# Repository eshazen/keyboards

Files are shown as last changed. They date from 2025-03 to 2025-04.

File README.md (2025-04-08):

# Keyboard project(s)

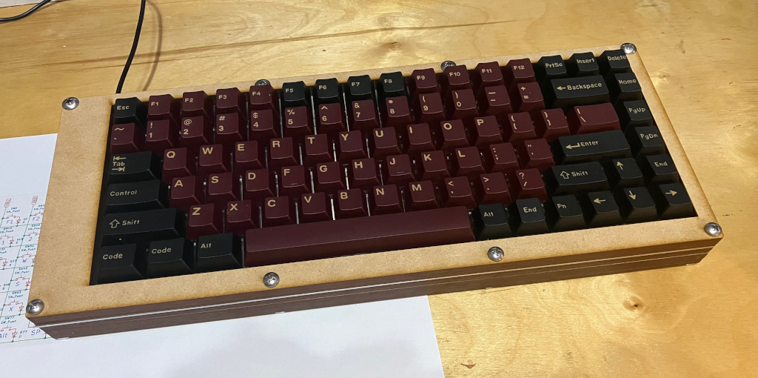
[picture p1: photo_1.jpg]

<p>

## Status

All done, working!  Used QMK for the firmware.  
<br>See `my_84/qmk/eric_84/key` for modified
`keyboard.json` and `keymaps/default/keymap.c`.  
<br>See [README_QMK](README_QMK.md).

To change layout, edit `~/qmk_firmware/keyboards/eric_84_key/keymaps/default/keymap.c`.
Then re-flash with:

    qmk flash -kb eric_84_key -km default

(This can be done "live" as long as you have access to the Arduino reset button).

In summary, created the layout in KLE, generated the plate and case
geometry in `swillkb.com`, and the PCB using the `kbplacer` plugin for
KiCAD.  Firmware generated using `qmk`.

Waterjet cutter files for plate in `waterJet`.

## Tools Used:

* [KLE](https://www.keyboard-layout-editor.com)
* [Plate & Case Builder](http://builder.swillkb.com/) (from [github](https://github.com/vladantrhlik/Keyboard_case_generator?tab=readme-ov-file)).  This generates the DXF for the plate and stacked laser-cut case parts.
* [kbplacer plugin](https://github.com/adamws/kicad-kbplacer) for KiCAD layout

## References

* [PCB video](https://www.youtube.com/watch?v=u13yRbBiRYM&t=10s)
* [Case video](https://www.youtube.com/watch?v=NIIr19TdidY)
* [Building Keyboards with Lasers](https://kbd.news/Building-keyboards-with-lasers-2208.html)
* [Keyboard University](https://www.keyboard.university/)
* [Pro Micro up to 100 pins](https://golem.hu/guide/pro-micro/)

Also used 

## My 84 key

<ul>
    [{a:6},"Esc","F1","F2","F3","F4","F5","F6","F7","F8","F9","F10","F11","F12",{a:7},"PrtSc","Shell","Pause"],
    [{a:4},"~\n`","!\n1","@\n2","#\n3","$\n4","%\n5","^\n6","&\n7","*\n8","(\n9",")\n0","_\n-","+\n=",{a:6,w:2},"Backspace",{a:7},"Insert"],
    [{a:4,w:1.5},"Tab","Q","W","E","R","T","Y","U","I","O","P","{\n[","}\n]",{w:1.5},"|\n\\",{a:6},"Delete"],
    [{w:1.75},"Control",{a:4},"A","S","D","F","G","H","J","K","L",":\n;","\"\n'",{a:6,w:2.25},"Enter","Page Up"],
    [{w:2.25},"Shift",{a:4},"Z","X","C","V","B","N","M","<\n,",">\n.","?\n/",{a:6,w:1.75},"Shift",{a:7},"↑",{a:6},"Page Down"],
    [{a:7,w:1.25},"Home",{a:6,w:1.25},"Menu",{w:1.25},"Alt",{a:7,w:6.25},"",{a:6},"Alt","Fn",{a:7},"End","←","↓","→"]

Using [http://builder.swillkb.com/](http://builder.swillkb.com/).

``` text
    Switch type: MX
	Stab:  Cherry + Costar
	Case: Sandwich
	Holes 8, 4.5mm, 10mm
	Edge:  Top: 10, Left: 30, Right: 10, Bottom: 25
	Corners: 2mm
```
<br>DXFs in `...Case/case1`
<br>PCB in `...kb_test`

This was OK except that the opening in the 'top' was a little tight.
Enlarged the CAD file by .05" on all sides.

</ul>

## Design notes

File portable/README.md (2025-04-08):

# Portable keyboard

Thinking about a portable version of the keyboard, possibly bluetooth.
Possible parts:

* Gateron KS33 low-profile switches
* Gateron low-profile keycap set

Messing with some 3D models it looks as if the total height above
the PCB is about 12mm and about 3mm to bottom of the pins/pegs,
so total around 15mm high.

60% keyboard is 11.25 x 3.75.

## Portable system?

Looking at a full portable system.  Some SBC options:

### RPi 5

Built-in Wifi, but need a hat for eMMC storage.

### Orange Pi

Many confusing pi 5 options.  Some have 2x eMMC
so can do WiFi and storage.  Relatively expensive. 

### ARM OS options

* https://dietpi.com/ - maybe try on a VM?

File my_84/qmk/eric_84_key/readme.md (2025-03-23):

# eric_84_key

eric_84_key

*A short description of the keyboard/project*

* Keyboard Maintainer: [Eric Hazen](https://github.com/eshazen)
* Hardware Supported: *The PCBs, controllers supported*
* Hardware Availability: *Links to where you can find this hardware*

Make example for this keyboard (after setting up your build environment):

    make eric_84_key:default

Flashing example for this keyboard:

    make eric_84_key:default:flash

See the [build environment setup](https://docs.qmk.fm/#/getting_started_build_tools) and the [make instructions](https://docs.qmk.fm/#/getting_started_make_guide) for more information. Brand new to QMK? Start with our [Complete Newbs Guide](https://docs.qmk.fm/#/newbs).

## Bootloader

Enter the bootloader in 3 ways:

* **Bootmagic reset**: Hold down the key at (0,0) in the matrix (usually the top left key or Escape) and plug in the keyboard
* **Physical reset button**: Briefly press the button on the back of the PCB - some may have pads you must short instead
* **Keycode in layout**: Press the key mapped to `QK_BOOT` if it is available

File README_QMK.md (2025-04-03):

# QMK for our keyboard

Following [instructions](https://johnmu.com/basic-qmk-keyboard/)

`qmk new-keyboard`

    Keyboard name:  eric_84_key

Told it our github info, using a dev-board pro-micro and no default layout.
The navigate to `keyboards/eric_84_key` and edit `keyboard.json` to as below
to set matrix pins etc.

Getting a working config was a pain.  The `matrix_pins` came from the schematic.
The `LAYOUT` section was created partly by the (now completely obsolete) https://qmk.fm/converter/
and hand-editing.

In `layout.c` started with a similar layout and hand-edited the changes.

Copied the working `keyboard.json` and `layout.c` to Git at `my_84/qmk/eric_84_key`
in this repo.  

Build instructions:

    qmk compile -kb eric_84_key -km default
	qmk flash -kb eric_84_key -km default
	
No problem reloading "live" keyboard as long as you have access to the reset button.

## Notes on on Xubuntu 24.04 update

(install gcc-avr, avr-libc, avrdude)

Had to use pipx to install in a virtual environment since there doesn't
seem to be an Ubuntu package for qmk.

	$ sudo apt install pipx
    $ pipx install qmk
    $ sudo usermod -a -G dialout $USER

Then fix the link in `.local/bin` to `../share/pipx/venvs/qmk/bin/qmk`

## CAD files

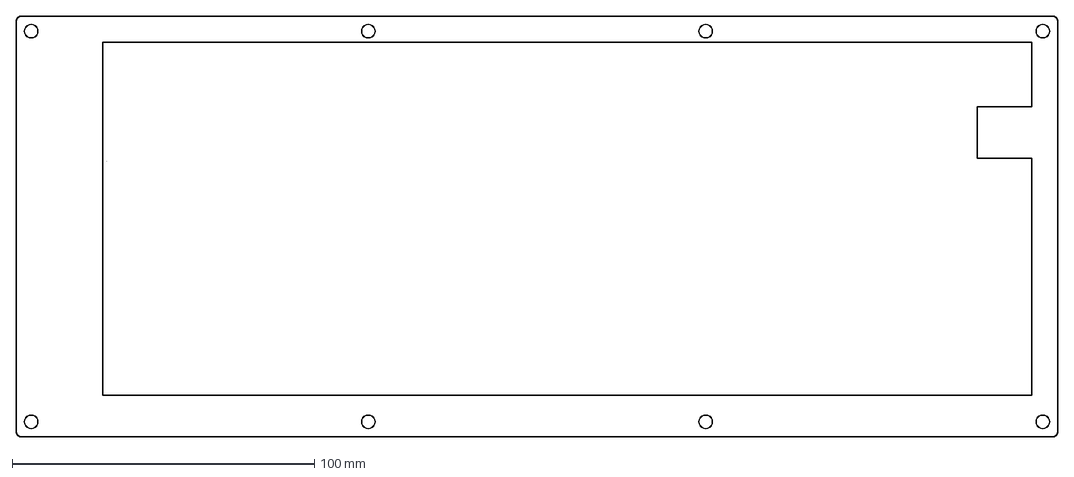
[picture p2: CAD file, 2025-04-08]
Case/case1/top_enlarge_blank.dxf
344.8 x 139.3 mm

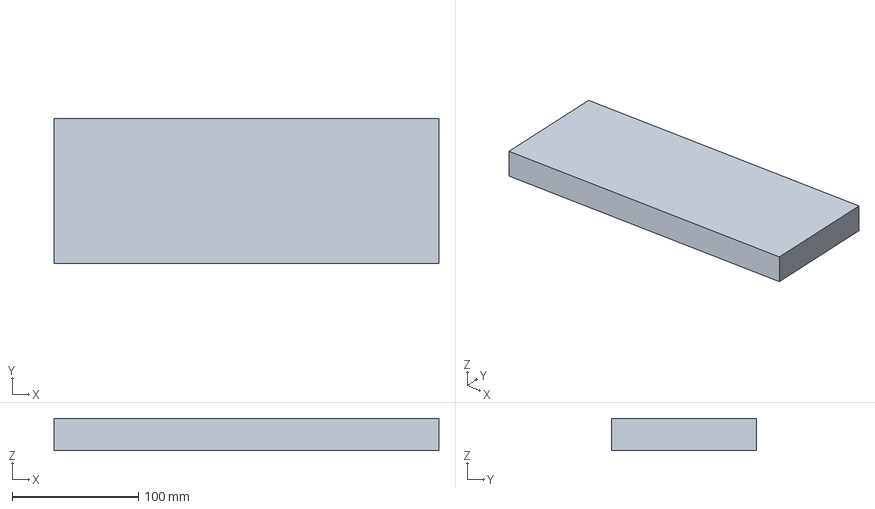
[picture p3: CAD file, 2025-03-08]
Case/test.3mf
305.0 x 115.0 x 25.4 mm

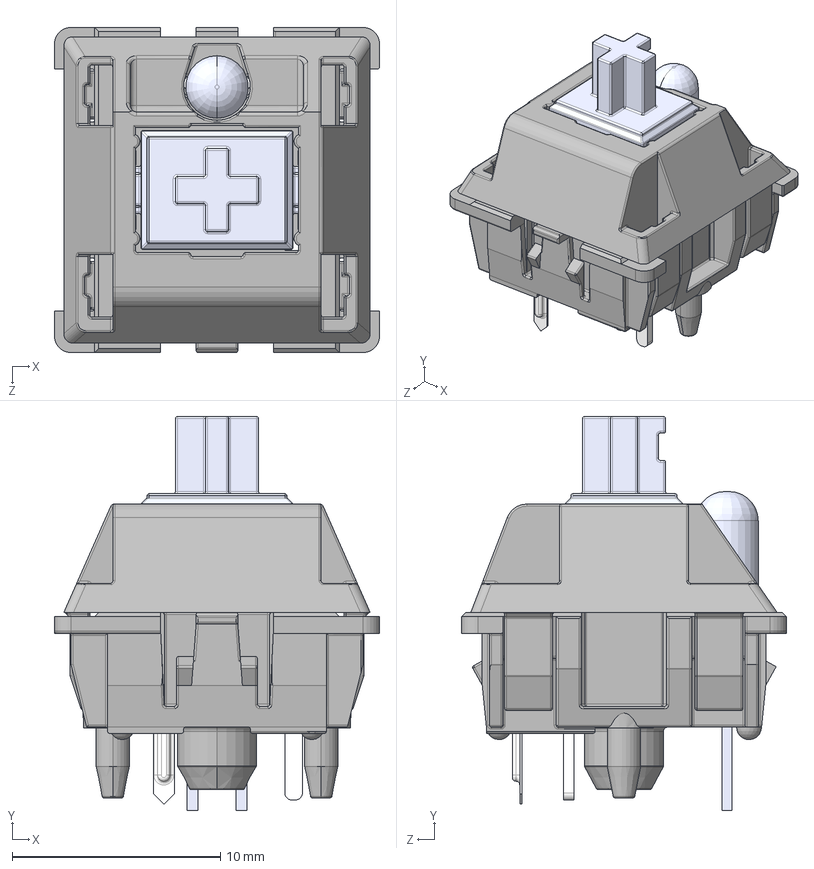
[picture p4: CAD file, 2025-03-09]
kb_test/cherry_mx.step
15.6 x 18.9 x 15.6 mm
MX 轴 按键′_ü___¨1
MX 轴 轴体áì_¨￠¨__
MX粣 拸簽LEDLEDLED
MX轴 轴体 底部 μ×2__默认_á2____è_
针脚___默认__è_

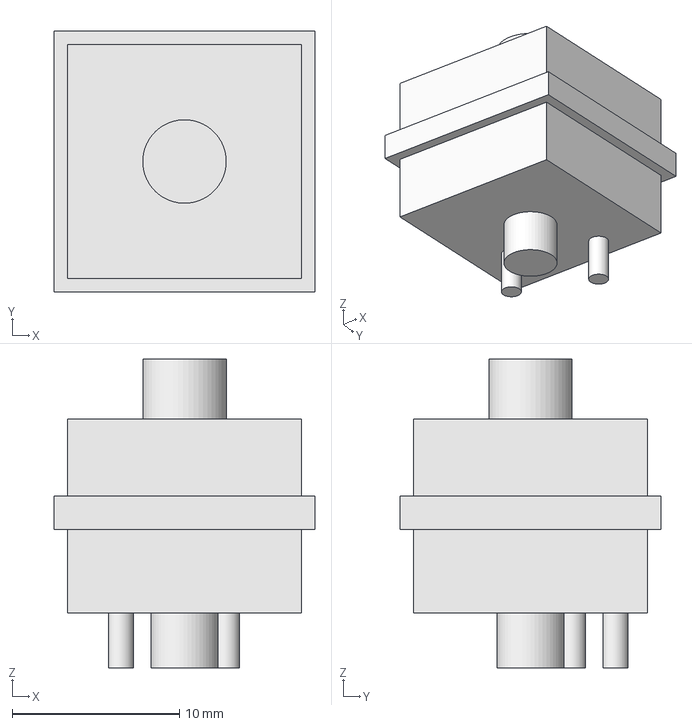
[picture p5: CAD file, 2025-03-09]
kb_test/models/cherry_simple.step
15.6 x 15.6 x 18.5 mm

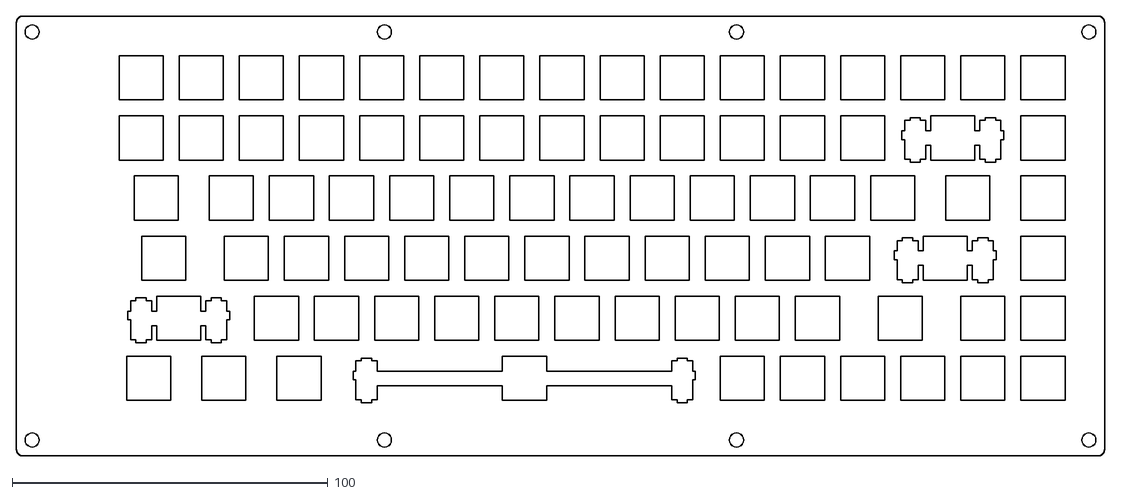
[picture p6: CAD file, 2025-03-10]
plate_fake/switch.dxf
344.8 x 139.3

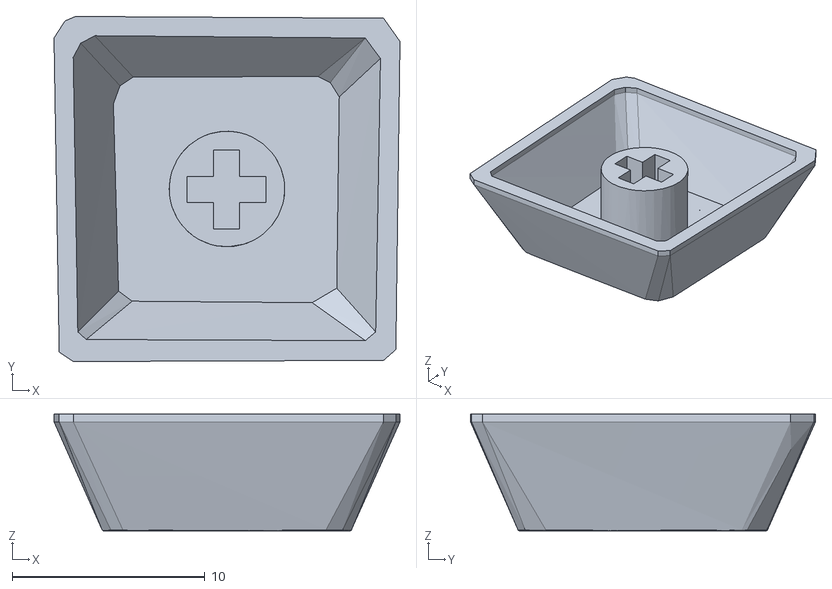
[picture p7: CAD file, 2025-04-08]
portable/gateron-key-cap.stl
18.0 x 17.9 x 6.05

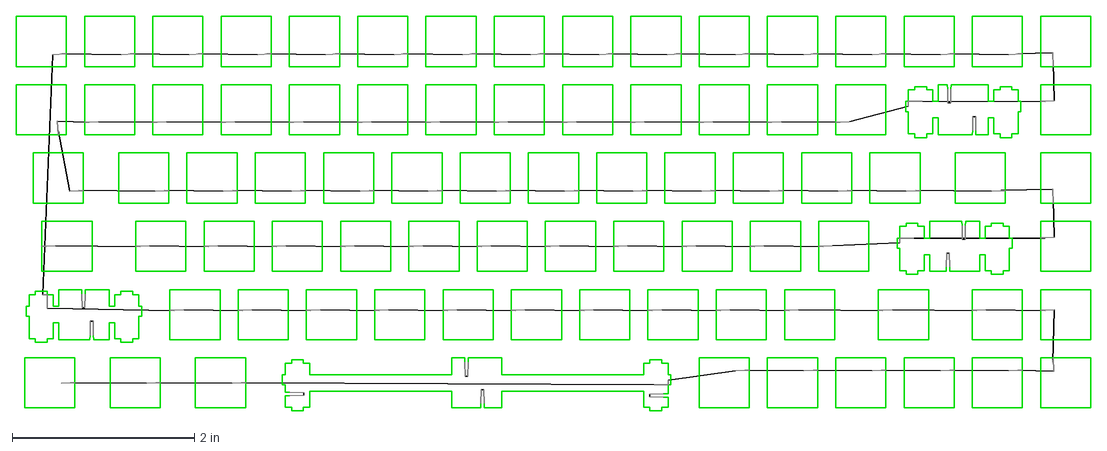
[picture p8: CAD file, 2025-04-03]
waterJet/switch_cutouts_imported_dxf_tabs.dxf
11.8 x 4.33 in

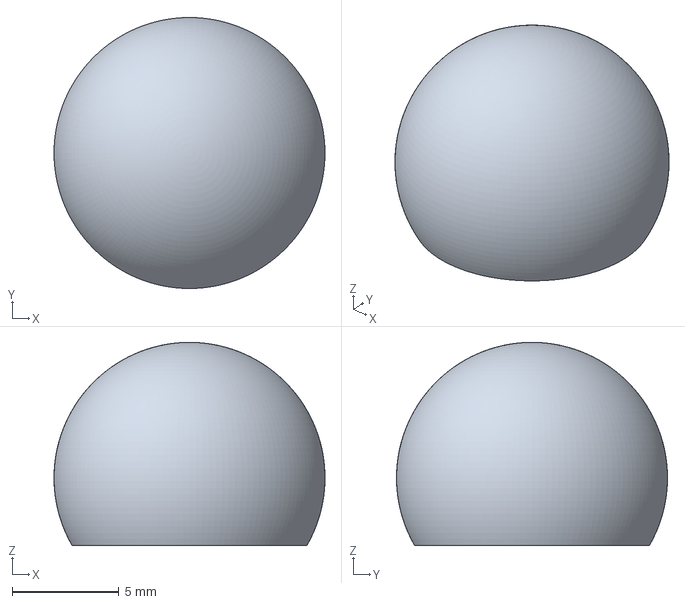
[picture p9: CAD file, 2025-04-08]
Case/case1/foot.3mf
12.7 x 12.7 x 9.52 mm

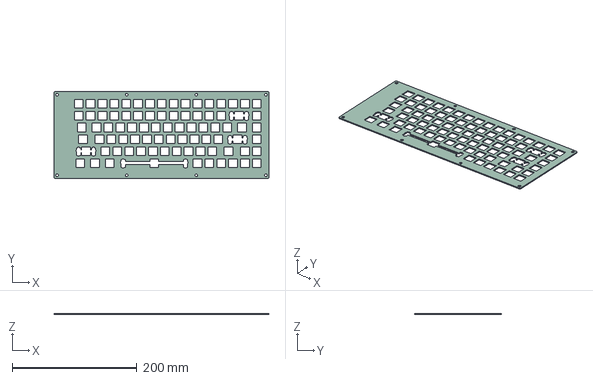
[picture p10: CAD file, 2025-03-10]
plate_fake/plate.step
344.8 x 139.3 x 1.60 mm

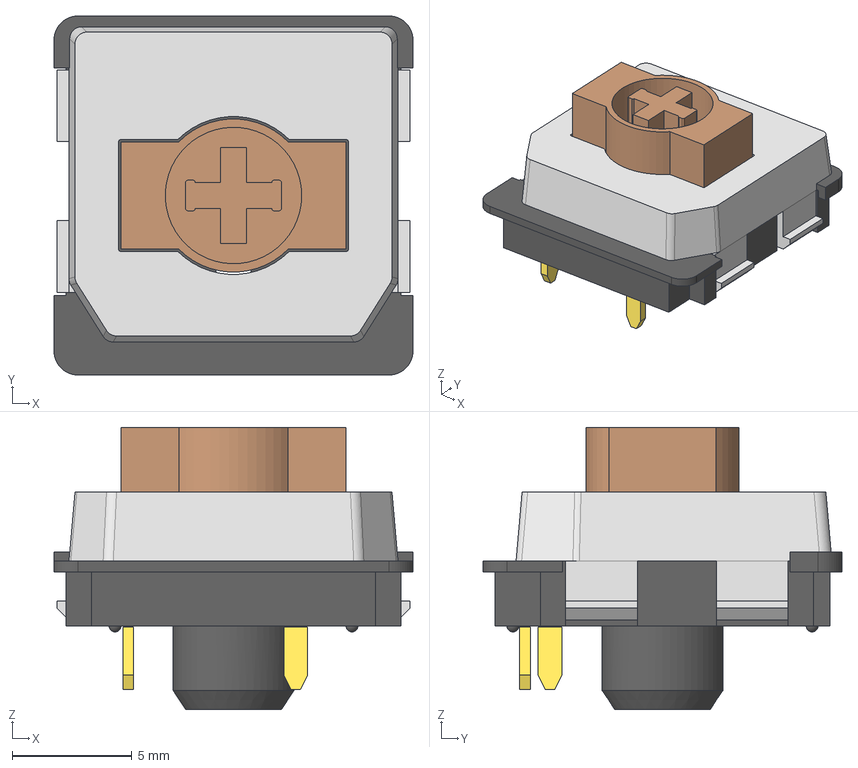
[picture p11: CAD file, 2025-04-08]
portable/ks33.step
15.0 x 15.0 x 11.8 mm
f0684a6a-028c-11ee-ae0e-34c93d8226b1_part
f06a1f0c-028c-11ee-ae0e-34c93d8226b1_part
f1cc5b76-028c-11ee-ae0e-34c93d8226b1_part
f1cc5d06-028c-11ee-ae0e-34c93d8226b1_part
f1cc5d92-028c-11ee-ae0e-34c93d8226b1_part

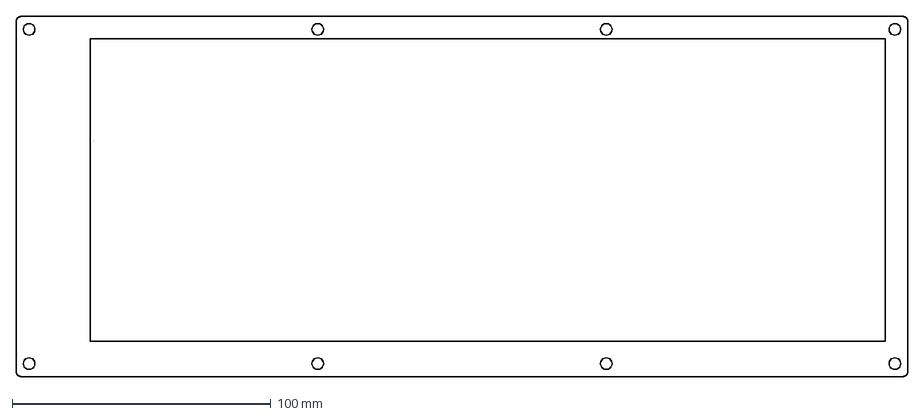
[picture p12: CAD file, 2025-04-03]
Case/case1/top_enlarge.dxf
344.8 x 139.3 mm

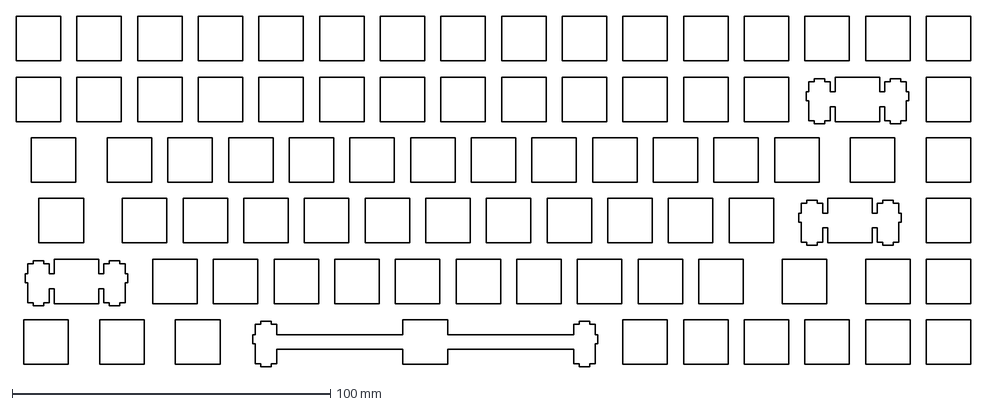
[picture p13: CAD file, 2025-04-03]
Case/case1/switch_cutouts.dxf
299.7 x 110.0 mm

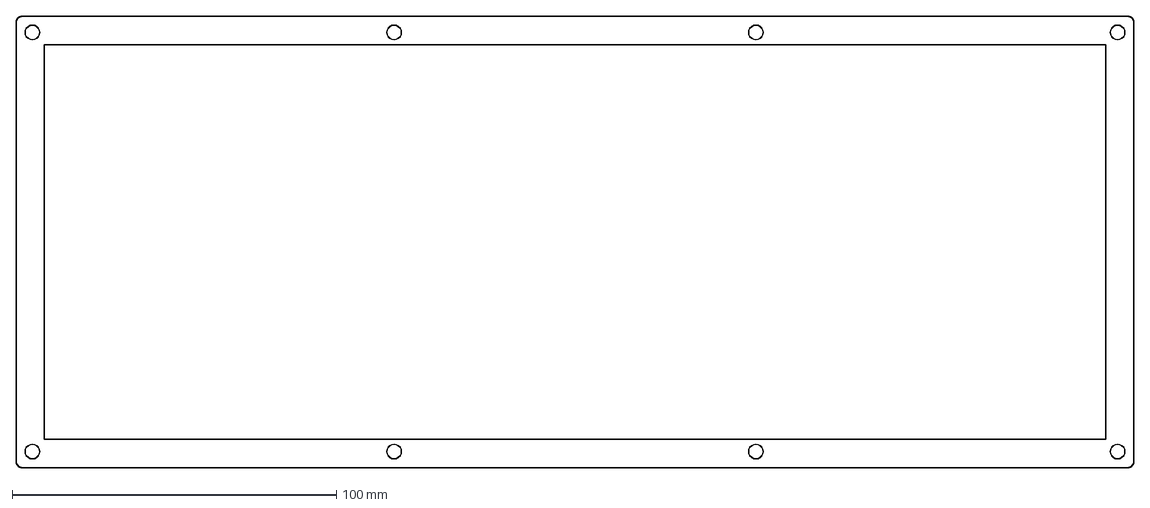
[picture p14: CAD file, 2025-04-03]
Case/case1/closed_enlarge.dxf
344.8 x 139.3 mm

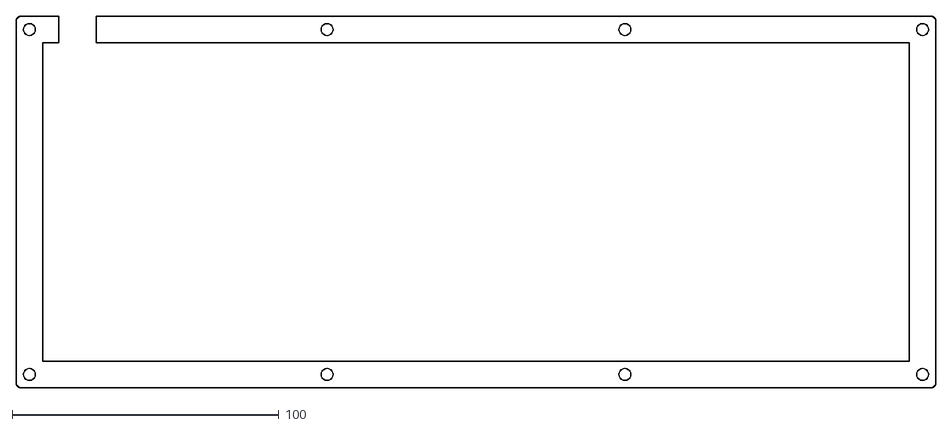
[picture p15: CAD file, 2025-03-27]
Case/case1/open.dxf
344.8 x 139.3

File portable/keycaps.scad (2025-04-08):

include </home/hazen/work/KeyV2/includes.scad>
 
legends = ["0", "1", "2", "3", "4", "5", "6", "7", "8", "9"];


// // use slop if not using a 0.2mm nozzle!
// bar_support() rounded_cherry() row_profile("mt3") tined_stem_support() {
//     key(true);
// }

 
for (x = [0:1:3]) {
  for (y = [0:1:3]) {
    bar_support() rounded_cherry(0.45) tined_stem_support() translate_u(x,y) legend(legends[y*4+x])   dsa_row() {
      // swap the debug()s to render     opposite part
//      debug()  
	 key(true);
//      debug() dished() {
//        legends($inset_legend_depth);
//      }
    }
  }
}

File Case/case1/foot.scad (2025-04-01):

mm = 25.4;
$fn = 128;
e = 0.1;

hole_dia = 0.160*mm;
outer_dia = 0.50*mm;
hole_dep = 0.125*mm;
foot_dep = 0.25*mm;

module foot() {
     difference() {
	  translate( [0, 0, hole_dep])
	       sphere( d=outer_dia);
	  translate( [0, 0, -e])
	       cylinder( d=hole_dia, h=hole_dep);
	  translate( [-outer_dia, -outer_dia, -10])
	       cube( [outer_dia*2, outer_dia*2, 10]);
     }
}

foot();

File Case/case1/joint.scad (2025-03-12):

//
// create overlap joint
//
// joint( w, l, h, right, clear, tap)
//   create (one half of) an overlap joint with drilled holes
//
//   (w, l, h) are (x, y, z) size of entire joint
//   right=true specifies right size
//   (clear, tap) are hole diameters (thru hole from bottom on left side)
//
// (expects mm=25.4)

joint_e = 0.1;

joint_cs_dep = 0.1*mm;		/* countersink depth */
joint_cs_angle = 82;		/* countersink angle */

// make an "ell" for a joint
// size:  wid, leng, dep
// hole:  dia = diameter, outside=1 for start outside, pct = percent to drill
module joint_ell( wid, leng, dep, dia, outside, pct) {
     difference() {
	  cube( [wid, leng, dep]);
	  translate( [wid/2, -e, dep/2])
	       cube( [wid/2+joint_e, leng+2*e, dep/2+joint_e]);
	  // deal with the hole
	  if( outside) {
	       translate( [3*wid/4, leng/2, -e]) {
		    cylinder( d=dia, h = (((pct/2)+1)/100+joint_e)*dep);
		    // countersink
		    ang = 90-joint_cs_angle/2;
		    d_rad = joint_cs_dep/tan(ang);
		    cylinder( d1=dia+2*d_rad, d2=dia, h=joint_cs_dep);
	       }
	  } else {
	       translate( [3*wid/4, leng/2, (dep/2)*(((100-pct)+1)/100)-e])
		    cylinder( d=dia, h = dep/2+2*e);
	  }
     }
}

module joint_flip( wid, leng, dep, flip, dia, outside, pct) {
     if( flip ) {
	  joint_ell( wid, leng, dep, dia, flip, pct);
     } else {
	  translate( [wid, 0, dep])
	       rotate( [180, 0, 180])
	       joint_ell( wid, leng, dep, dia, flip, pct);
     }
}

module joint( w, l, h, right, clear, tap) {
     if( right) {
	  joint_flip(2*w/3, l, h, true, clear, 1, 100);
     } else {
	  joint_flip( 2*w/3, l, h, false, tap, 0, 75);
     }
}

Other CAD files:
Case/case1/foot_round.3mf
Case/case1/case_left.3mf
Case/case1/case_right.3mf
Case/case1/plate_test.3mf
Case/case1/plate.scad
Case/case1/bottom.dxf
Case/case1/closed.dxf
Case/case1/plate.3mf
Case/case1/plate.step
Case/case1/plate.stl
Case/case1/plate_drawing.dxf
Case/case1/test.dxf
Case/case1/test_left.3mf
Case/case1/test_right.3mf
Case/case1/top.dxf
Case/test.scad
kb_test/models/cherry_simple.scad
plate_fake/plate.3mf
portable/ks33.stl
portable/trial_stackup.scad

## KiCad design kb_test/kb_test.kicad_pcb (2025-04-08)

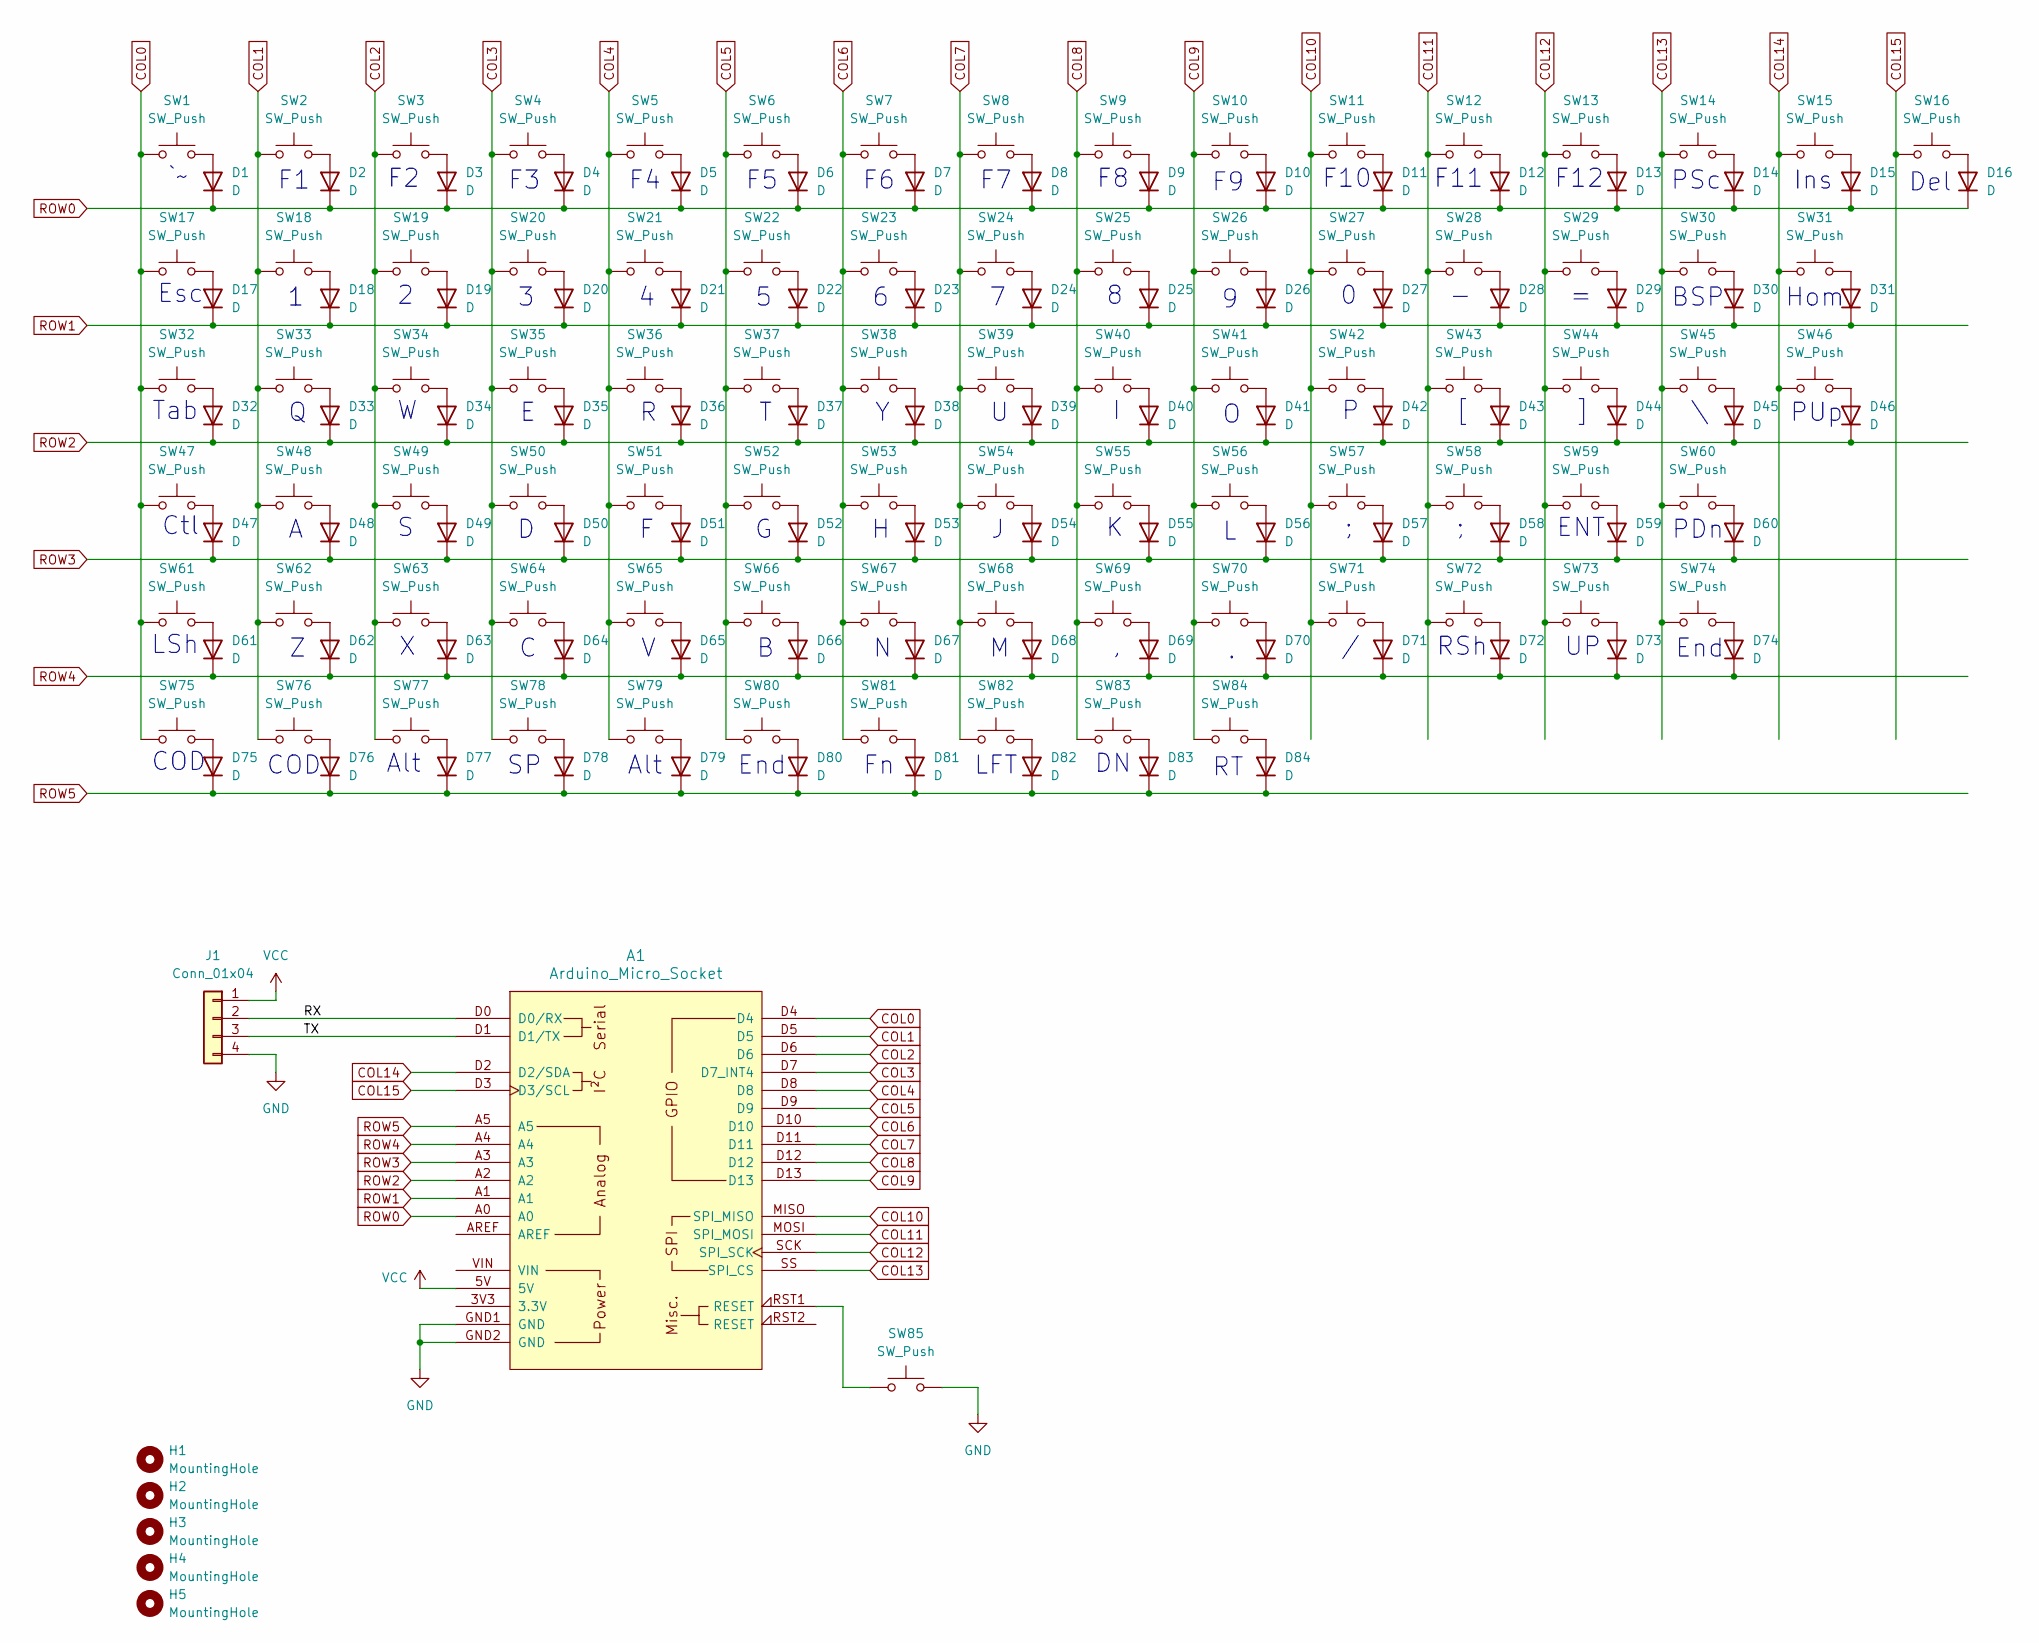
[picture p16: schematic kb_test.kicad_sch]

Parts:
A1: Arduino_Micro_Socket
D1, D2, D3, D4, D5, D6, D7, D8, D9, D10, D11, D12, D13, D14, D15, D16, D17, D18, D19, D20, D21, D22, D23, D24, D25, D26, D27, D28, D29, D30, D31, D32, D33, D34, D35, D36, D37, D38, D39, D40, D41, D42, D43, D44, D45, D46, D47, D48, D49, D50, D51, D52, D53, D54, D55, D56, D57, D58, D59, D60, D61, D62, D63, D64, D65, D66, D67, D68, D69, D70, D71, D72, D73, D74, D75, D76, D77, D78, D79, D80, D81, D82, D83, D84: D; D_DO-41_SOD81_P7.62mm_Horizontal
H1, H2, H3, H4, H5: MountingHole; MountingHole_4.3mm_M4
J1: Conn_01x04; PinHeader_1x04_P2.54mm_Vertical
SW1, SW2, SW3, SW4, SW5, SW6, SW7, SW8, SW9, SW10, SW11, SW12, SW13, SW14, SW15, SW16, SW17, SW18, SW19, SW20, SW21, SW22, SW23, SW24, SW25, SW26, SW27, SW28, SW29, SW30, SW31, SW32, SW33, SW34, SW35, SW36, SW37, SW38, SW39, SW40, SW41, SW42, SW43, SW44, SW45, SW46, SW47, SW48, SW49, SW50, SW51, SW52, SW53, SW54, SW55, SW56, SW57, SW58, SW59, SW60, SW61, SW62, SW63, SW64, SW65, SW66, SW67, SW68, SW69, SW70, SW71, SW72, SW73, SW74, SW75, SW76, SW77, SW78, SW79, SW80, SW81, SW82, SW83, SW84: SW_Push; SW_Cherry_MX_1.00u_PCB
SW85: SW_Push; SW_Tactile_Straight_KSA0Axx1LFTR

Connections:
/RX: A1.D0 (D0/RX), J1.2
/TX: A1.D1 (D1/TX), J1.3
COL0: A1.D4, SW1.1, SW17.1, SW32.1, SW47.1, SW61.1, SW75.1
COL1: A1.D5, SW2.1, SW18.1, SW33.1, SW48.1, SW62.1, SW76.1
COL2: A1.D6, SW3.1, SW19.1, SW34.1, SW49.1, SW63.1, SW77.1
COL3: A1.D7 (D7_INT4), SW4.1, SW20.1, SW35.1, SW50.1, SW64.1, SW78.1
COL4: A1.D8, SW5.1, SW21.1, SW36.1, SW51.1, SW65.1, SW79.1
COL5: A1.D9, SW6.1, SW22.1, SW37.1, SW52.1, SW66.1, SW80.1
COL6: A1.D10, SW7.1, SW23.1, SW38.1, SW53.1, SW67.1, SW81.1
COL7: A1.D11, SW8.1, SW24.1, SW39.1, SW54.1, SW68.1, SW82.1
COL8: A1.D12, SW9.1, SW25.1, SW40.1, SW55.1, SW69.1, SW83.1
COL9: A1.D13, SW10.1, SW26.1, SW41.1, SW56.1, SW70.1, SW84.1
COL10: A1.MISO (SPI_MISO), SW11.1, SW27.1, SW42.1, SW57.1, SW71.1
COL11: A1.MOSI (SPI_MOSI), SW12.1, SW28.1, SW43.1, SW58.1, SW72.1
COL12: A1.SCK (SPI_SCK), SW13.1, SW29.1, SW44.1, SW59.1, SW73.1
COL13: A1.SS (SPI_CS), SW14.1, SW30.1, SW45.1, SW60.1, SW74.1
COL14: A1.D2 (D2/SDA), SW15.1, SW31.1, SW46.1
COL15: A1.D3 (D3/SCL), SW16.1
GND: A1.GND1 (GND), A1.GND2 (GND), J1.4, SW85.2
unnamed: A1.RST1 (RESET), SW85.1
unnamed: D1.2 (A), SW1.2
unnamed: D2.2 (A), SW2.2
unnamed: D3.2 (A), SW3.2
unnamed: D4.2 (A), SW4.2
unnamed: D5.2 (A), SW5.2
unnamed: D6.2 (A), SW6.2
unnamed: D7.2 (A), SW7.2
unnamed: D8.2 (A), SW8.2
unnamed: D9.2 (A), SW9.2
unnamed: D10.2 (A), SW10.2
unnamed: D11.2 (A), SW11.2
unnamed: D12.2 (A), SW12.2
unnamed: D13.2 (A), SW13.2
unnamed: D14.2 (A), SW14.2
unnamed: D15.2 (A), SW15.2
unnamed: D16.2 (A), SW16.2
unnamed: D17.2 (A), SW17.2
unnamed: D18.2 (A), SW18.2
unnamed: D19.2 (A), SW19.2
unnamed: D20.2 (A), SW20.2
unnamed: D21.2 (A), SW21.2
unnamed: D22.2 (A), SW22.2
unnamed: D23.2 (A), SW23.2
unnamed: D24.2 (A), SW24.2
unnamed: D25.2 (A), SW25.2
unnamed: D26.2 (A), SW26.2
unnamed: D27.2 (A), SW27.2
unnamed: D28.2 (A), SW28.2
unnamed: D29.2 (A), SW29.2
unnamed: D30.2 (A), SW30.2
unnamed: D31.2 (A), SW31.2
unnamed: D32.2 (A), SW32.2
unnamed: D33.2 (A), SW33.2
unnamed: D34.2 (A), SW34.2
unnamed: D35.2 (A), SW35.2
unnamed: D36.2 (A), SW36.2
unnamed: D37.2 (A), SW37.2
unnamed: D38.2 (A), SW38.2
unnamed: D39.2 (A), SW39.2
unnamed: D40.2 (A), SW40.2
unnamed: D41.2 (A), SW41.2
unnamed: D42.2 (A), SW42.2
unnamed: D43.2 (A), SW43.2
unnamed: D44.2 (A), SW44.2
unnamed: D45.2 (A), SW45.2
unnamed: D46.2 (A), SW46.2
unnamed: D47.2 (A), SW47.2
unnamed: D48.2 (A), SW48.2
unnamed: D49.2 (A), SW49.2
unnamed: D50.2 (A), SW50.2
unnamed: D51.2 (A), SW51.2
unnamed: D52.2 (A), SW52.2
unnamed: D53.2 (A), SW53.2
unnamed: D54.2 (A), SW54.2
unnamed: D55.2 (A), SW55.2
unnamed: D56.2 (A), SW56.2
unnamed: D57.2 (A), SW57.2
unnamed: D58.2 (A), SW58.2
unnamed: D59.2 (A), SW59.2
unnamed: D60.2 (A), SW60.2
unnamed: D61.2 (A), SW61.2
unnamed: D62.2 (A), SW62.2
unnamed: D63.2 (A), SW63.2
unnamed: D64.2 (A), SW64.2
unnamed: D65.2 (A), SW65.2
unnamed: D66.2 (A), SW66.2
unnamed: D67.2 (A), SW67.2
unnamed: D68.2 (A), SW68.2
unnamed: D69.2 (A), SW69.2
unnamed: D70.2 (A), SW70.2
unnamed: D71.2 (A), SW71.2
unnamed: D72.2 (A), SW72.2
unnamed: D73.2 (A), SW73.2
unnamed: D74.2 (A), SW74.2
unnamed: D75.2 (A), SW75.2
unnamed: D76.2 (A), SW76.2
unnamed: D77.2 (A), SW77.2
unnamed: D78.2 (A), SW78.2
unnamed: D79.2 (A), SW79.2
unnamed: D80.2 (A), SW80.2
unnamed: D81.2 (A), SW81.2
unnamed: D82.2 (A), SW82.2
unnamed: D83.2 (A), SW83.2
unnamed: D84.2 (A), SW84.2
ROW0: A1.A0, D1.1 (K), D2.1 (K), D3.1 (K), D4.1 (K), D5.1 (K), D6.1 (K), D7.1 (K), D8.1 (K), D9.1 (K), D10.1 (K), D11.1 (K), D12.1 (K), D13.1 (K), D14.1 (K), D15.1 (K), D16.1 (K)
ROW1: A1.A1, D17.1 (K), D18.1 (K), D19.1 (K), D20.1 (K), D21.1 (K), D22.1 (K), D23.1 (K), D24.1 (K), D25.1 (K), D26.1 (K), D27.1 (K), D28.1 (K), D29.1 (K), D30.1 (K), D31.1 (K)
ROW2: A1.A2, D32.1 (K), D33.1 (K), D34.1 (K), D35.1 (K), D36.1 (K), D37.1 (K), D38.1 (K), D39.1 (K), D40.1 (K), D41.1 (K), D42.1 (K), D43.1 (K), D44.1 (K), D45.1 (K), D46.1 (K)
ROW3: A1.A3, D47.1 (K), D48.1 (K), D49.1 (K), D50.1 (K), D51.1 (K), D52.1 (K), D53.1 (K), D54.1 (K), D55.1 (K), D56.1 (K), D57.1 (K), D58.1 (K), D59.1 (K), D60.1 (K)
ROW4: A1.A4, D61.1 (K), D62.1 (K), D63.1 (K), D64.1 (K), D65.1 (K), D66.1 (K), D67.1 (K), D68.1 (K), D69.1 (K), D70.1 (K), D71.1 (K), D72.1 (K), D73.1 (K), D74.1 (K)
ROW5: A1.A5, D75.1 (K), D76.1 (K), D77.1 (K), D78.1 (K), D79.1 (K), D80.1 (K), D81.1 (K), D82.1 (K), D83.1 (K), D84.1 (K)
VCC: A1.5V, J1.1

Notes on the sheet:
PUp
End
Alt
Del
LSh
LFT
ENT
PSc
F12
Hom
COD
BSP
F11
RSh
Ctl
PDn
Tab
Esc
F10
Ins

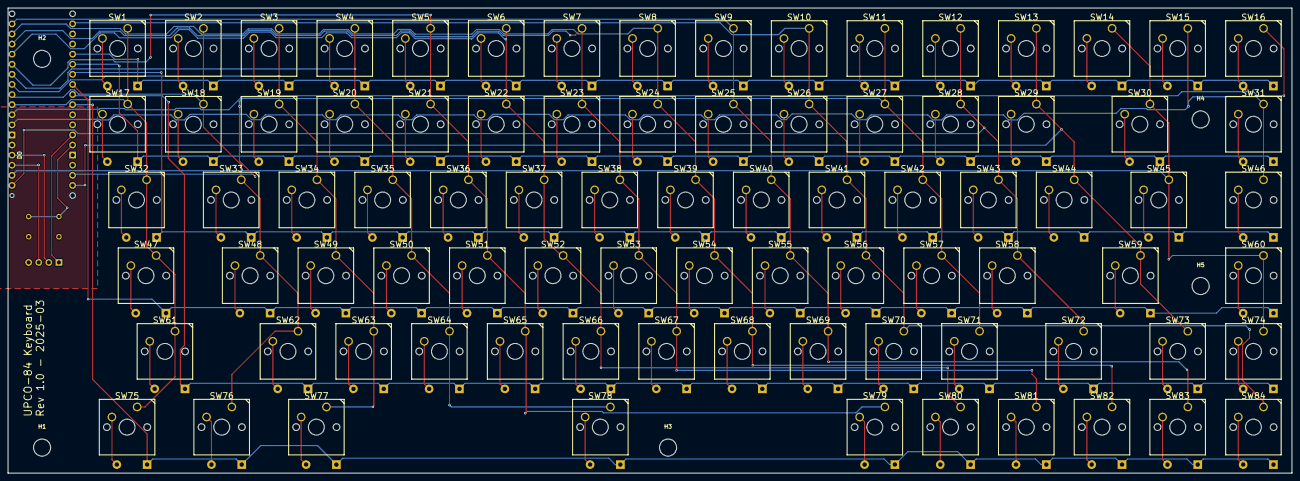
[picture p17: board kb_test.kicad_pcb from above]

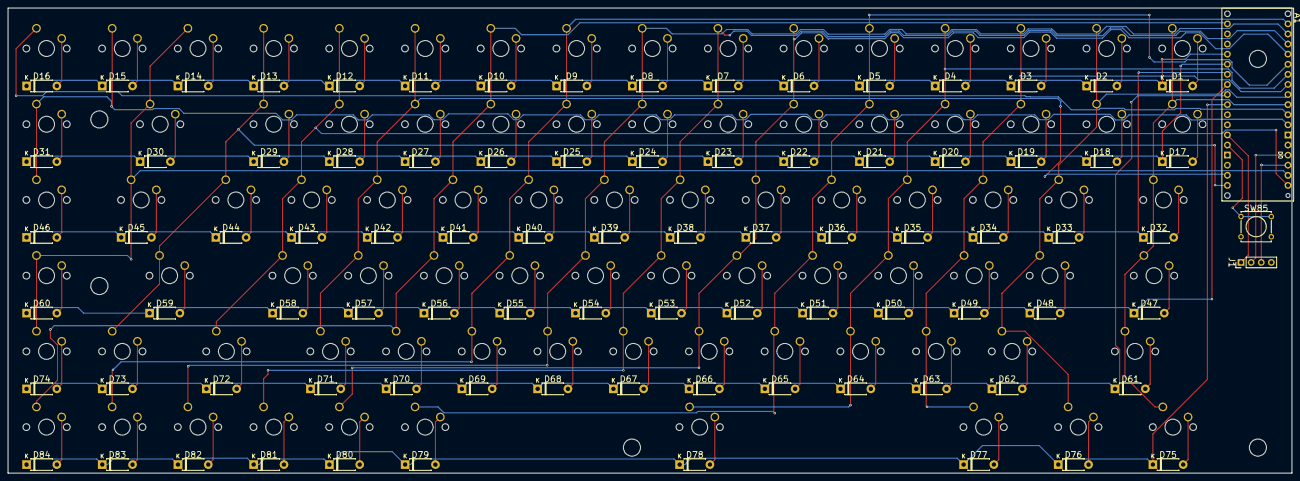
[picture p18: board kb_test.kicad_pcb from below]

Board: 2 copper layers, 323.0 x 117.0 mm, 176 parts (87 on the bottom side), 111 nets.

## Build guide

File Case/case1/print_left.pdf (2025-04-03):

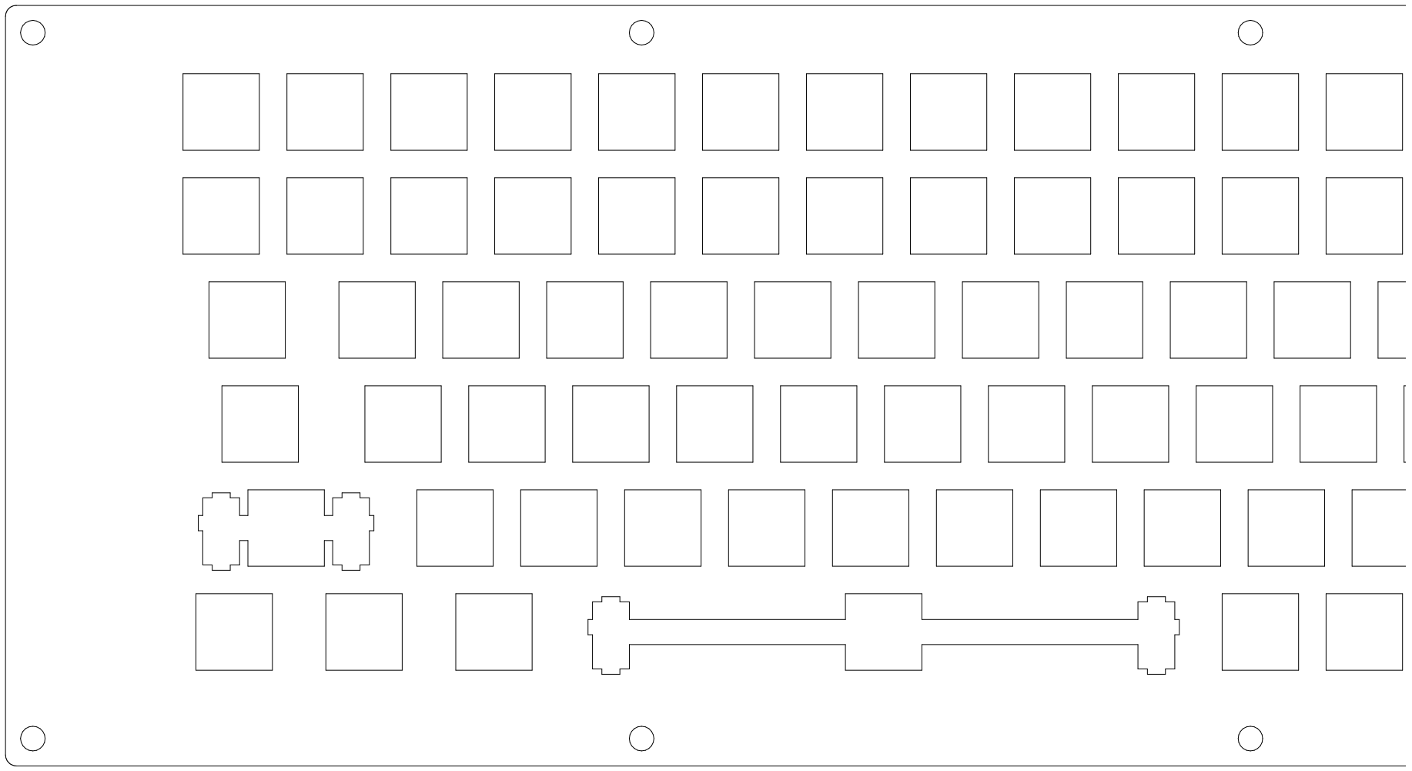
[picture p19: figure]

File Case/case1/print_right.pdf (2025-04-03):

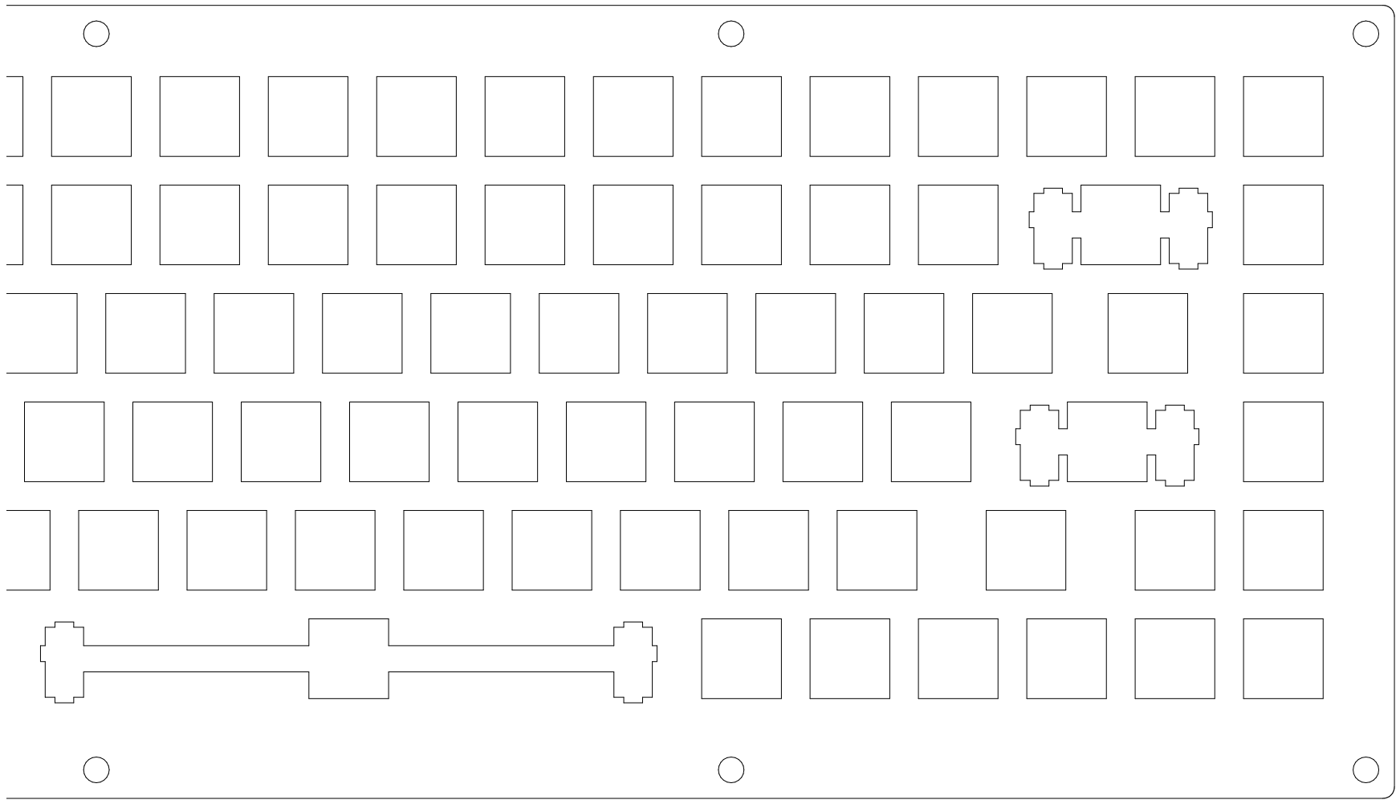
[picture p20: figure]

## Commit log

2025-03-04 test version of 84 key
    [kb_test.kicad_pcb, kb_test.kicad_sch]
2025-03-09 Tentative placement with diodes on front
    [cherry_mx.step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]
2025-03-09 candidate placement with diodes and MCU on bottom
    [kb_test.kicad_pcb]
2025-03-09 tentative placement with simple MX models
    [cherry_simple.scad, cherry_simple.step, kb_test.kicad_pcb]
2025-03-10 working on case
    [bottom.dxf, case_left.3mf, closed.dxf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]
2025-03-12 Update 'shrink' option, fix joint issues
    [case_left.3mf, case_right.3mf, joint.scad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]
2025-03-12 prelim gerbers
    [kb_test-B_Cu.gbr, kb_test-B_Mask.gbr, kb_test-B_Silkscreen.gbr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]
2025-03-23 Hardware as built; QMK firmware config OK
    [case_left.3mf, case_right.3mf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]
2025-03-27 tweak plates
    [case_left.3mf, open.dxf, plate.scad]
2025-03-28 save qmk config
    [kb_test.kicad_sch]
2025-04-01 update a few things, add waterjet files
    [closed_enlarge.dxf, switch_cutouts.dxf, switch_cutouts_imported_dxf_tabs.dxf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]
2025-04-07 top with missing home key
    [top_enlarge_blank.dxf]
2025-04-08 start portable
    [foot.3mf, gateron-key-cap.stl, keycaps.scad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]
2025-04-08 cleaning up
    [kb_test.kicad_pcb]
